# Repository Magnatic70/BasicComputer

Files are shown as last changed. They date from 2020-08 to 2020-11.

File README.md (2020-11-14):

# BasicComputer
A text-only basic computer with VGA-output using a ESP32/ESP8266 and a FPGA

## What it does
It is a simple computer with a BASIC-interpreter that is close to the one of the Sinclair ZX Spectrum. The computer is text-based only, but does support 8 colors for both foreground and background.

The computer has a 80x60 character display with a 640x480 resolution. You can use a PS2-keyboard connected to the FPGA-board or a HTML-based keyboard using a browser as input.

There are BASIC-commands for http-based communication (both incoming and outgoing), reading and writing of programs to SPIFFS, reading and writing of data to SPIFFS.

## Thanks to Robin Edwards for the BASIC-interpreter
I didn't write the core of the BASIC-interpreter myself, but it is based on https://github.com/robinhedwards/ArduinoBASIC by Robin Edwards.

I did adapt the interpreter so that it can be used on an ESP. An ESP needs variables to be 4 byte aligned in memory. The Arduino does not have that restriction. The interpreter stored variables directly into a pool of reserved memory which of course was almost never 4 byte aligned. By converting variables into separate bytes and then storing those bytes I managed to use the same approach with as little changes to the interpreter as possible.

I also added al lot of new commands and functions regarding mainly http-communication, reading and writing to SPIFFS and some other useful stuff. And most importantly, I wrote a new host-interface for the intepreter that allows the ESP to communicate with the FPGA and/or the HTML-keyboard-interface.

## Components, tools and software required
* ESP32: I use a D1 Mini ESP32 (https://www.aliexpress.com/item/32816065152.html)
* (Alternative) ESP8266: D1 Mini ESP8266 (https://www.aliexpress.com/item/32651747570.html)
* FPGA-board:  I use a A-C4E6E10 with an Cyclone IV EP4CE6E22C8 (https://www.aliexpress.com/item/4001125259366.html) but other FPGA-boards may also work. The FPGA-program needs 953 logical elements, 258 registers, 11 pins, 4688 bits of on-chip memory and 1 on-chip pll. The source in this repository has all pins assigned, but they most likely won't work for other boards. Also the optional 3D-printed case probably won't fit.
* USB-blaster or other JTAG-programmer for uploading to the FPGA
* VGA-monitor
* (Optional) PS/2 keyboard
* Five wires (M-F) to connect the ESP32 and FPGA-board
* Arduino-IDE to compile and upload to the ESP32
* Quartus Prime 19.1 Lite Edition with support for the Cyclone IV-family to compile and upload to the FPGA
* (Optional) 3D-printer to print the case for the computer
* (Optional) Two small screws to join the two parts of the case and four small screws to join the FPGA-board to the bottom of the case.

Using the ESP8266 instead of the ESP32 will result in a lot less memory available for BASIC-programs. The ESP32 has 113792 bytes available for BASIC where the ESP8266 has just 16384 bytes available.

## How to make it
### ESP
#### Compilation
1. Download all files from https://github.com/Magnatic70/magnatic-esp, except magnatic-esp.ino and add these files to the ones in this projects esp-source folder.
1. Use the Arduino-IDE to load, compile and upload BASCOMP002.ino to the ESP.

If you don't have a PS/2-keyboard
1. Follow the instructions in https://github.com/Magnatic70/magnatic-esp/blob/master/README.md chapters "First deployment" and "Initial configuration"
1. Upload the file keyboard.html with WinSCP to the ESP

The ESP is now ready for use.

### FPGA
1. Load asciiVGAVideoCard.qpf in Quartus Prime and Start Compilation
1. File --> Convert programming files --> Open conversion Setup Data -->  sof2jic4cycloneiv.cof --> Open --> Generate
1. Programmer --> Add file --> output_files/asciiVGACard.jic --> Open --> Check the Program/Configure checkbox in the second line --> Start

The FPGA-board is now ready for use.

### Connect ESP and FPGA
For a D1 Mini ESP32
1. Connect FPGA-pin GND to ESP-pin GND
1. Connect FPGA-pin 3.3V to ESP-pin 3.3V
1. Connect FPGA-pin 30 to ESP-pin IO17 (TX UART2)
1. Connect FPGA-pin 28 to ESP-pin IO16 (RX UART2)
1. Connect FPGA-pin 32 to ESP-pin IO21

For a D1 Mini ESP8266
1. Connect FPGA-pin GND to ESP-pin GND
1. Connect FPGA-pin 3.3V to ESP-pin 3.3V
1. Connect FPGA-pin 30 to ESP-pin TX
1. Connect FPGA-pin 28 to ESP-pin RX
1. Connect FPGA-pin 32 to ESP-pin D1

Your BASIC-computer should now work. Connect a VGA-monitor and (optional) PS/2-keyboard to the FPGA-board and power on the board.

If you have a PS/2-keyboard you can start using the BASIC-computer right awys. You can connect the computer to your Wifi-network using the commands SETSSID and SETSSIDPW.

If you don't have a PS/2-keyboard you can use the HTML-based keyboard (if you did upload keyboard.html to the ESP) by going to the URL at the top of the screen. As long as the browser-window is active all keyboard-activity is sent to the ESP. If you haven't configured the wifi-settings yet: Connect your wifi to the Wifi-network with BASCOMP in the name. Password: esp

Type HELP or HELP2 for the available BASIC-commands and functions and HELP3 for cursor navigation cues.

### (Optional) 3D-print
1. Print the bottom.stl with a layer height of 0.2mm, no supports needed, infill 10%
1. Print the top.stl with a layer height of 0.2mm, SUPPORTS NEEDED!, infill 10%
1. Remove supports

### (Optional) Place ESP and FPGA in 3D-printed case
1. Use four small screws to mount the FPGA-board to the bottom of the case.
1. Place the ESP in the small space in one of the sides of the top of the case. The springiness of the wires will keep the ESP in that position.
1. Align top and bottom and use two screws at the bottom of the case to join the two parts.

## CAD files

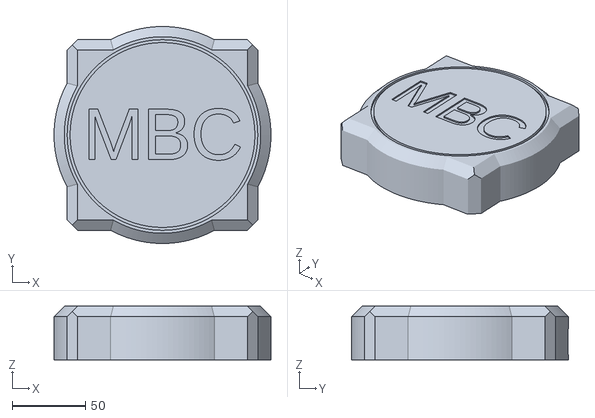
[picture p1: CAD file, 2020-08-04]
3d-printing-code/top.stl
148.0 x 148.0 x 36.5

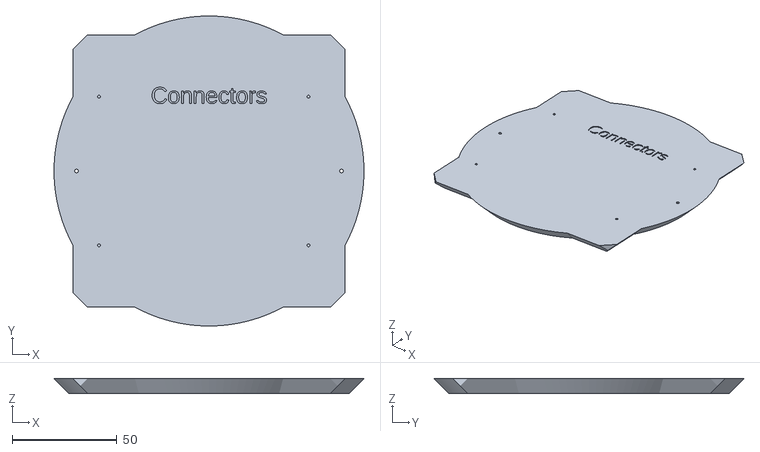
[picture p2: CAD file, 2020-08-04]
3d-printing-code/bottom.stl
148.0 x 148.0 x 7.00

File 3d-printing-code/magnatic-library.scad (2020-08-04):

module myCylinder(radius,height,chamfer){
  union(){
    cylinder(h=chamfer,r1=radius-chamfer,r2=radius);
    translate([0,0,chamfer]){
      cylinder(h=height-2*chamfer,r=radius);
    }
    translate([0,0,height-chamfer]){
      cylinder(h=chamfer,r1=radius,r2=radius-chamfer);
    }
  }
}

module myCylinderCTop(radius,height,chamfer){
  union(){
    cylinder(h=height-chamfer,r=radius);
    translate([0,0,height-chamfer]){
      cylinder(h=chamfer,r1=radius,r2=radius-chamfer);
    }
  }
}

module myCylinderCBottom(radius,height,chamfer){
  union(){
    cylinder(h=chamfer,r1=radius-chamfer,r2=radius);
    translate([0,0,chamfer]){
      cylinder(h=height-chamfer,r=radius);
    }
  }
}

module hollowCylinder(height,outerRadius,innerRadius,chamfer){
  difference(){
    myCylinder(outerRadius,height,chamfer);
    union(){
      translate([0,0,-0.001]){
        cylinder(h=chamfer+0.002,r1=innerRadius+chamfer,r2=innerRadius);
      }
      translate([0,0,chamfer-0.001]){
        cylinder(h=height-2*chamfer+0.002,r=innerRadius);
      }
      translate([0,0,height-chamfer-0.001]){
        cylinder(h=chamfer+0.002,r1=innerRadius,r2=innerRadius+chamfer);
      }
    }
  }
}

module chamferCube(sizeX, sizeY, sizeZ, chamferHeight, center, chamferX, chamferY, chamferZ) {
  chamferX = (chamferX == undef) ? [1, 1, 1, 1] : chamferX;
  chamferY = (chamferY == undef) ? [1, 1, 1, 1] : chamferY;
  chamferZ = (chamferZ == undef) ? [1, 1, 1, 1] : chamferZ;
  chamferCLength = sqrt(chamferHeight * chamferHeight * 2);
  tx=center?-(sizeX/2):0;
  ty=center?-(sizeY/2):0;
  tz=center?-(sizeZ/2):0;
  translate([tx,ty,tz]){
    difference() {
      cube([sizeX, sizeY, sizeZ]);
      for(x = [0 : 3]) {
        chamferSide1 = min(x, 1) - floor(x / 3); // 0 1 1 0
        chamferSide2 = floor(x / 2); // 0 0 1 1
        if(chamferX[x]) {
          translate([-0.1, chamferSide1 * sizeY, -chamferHeight + chamferSide2 * sizeZ]){
            rotate([45, 0, 0]){
              cube([sizeX + 0.2, chamferCLength, chamferCLength]);
            }
          }
        }
        if(chamferY[x]) {
          translate([-chamferHeight + chamferSide2 * sizeX, -0.1, chamferSide1 * sizeZ]){
            rotate([0, 45, 0]){
              cube([chamferCLength, sizeY + 0.2, chamferCLength]);
            }
          }
        }
        if(chamferZ[x]) {
          translate([chamferSide1 * sizeX, -chamferHeight + chamferSide2 * sizeY, -0.1]){
            rotate([0, 0, 45]){
              cube([chamferCLength, chamferCLength, sizeZ + 0.2]);
            }
          }
        }
      }
    }
  }
}

module wedge(width1,width2,depth,height){
  linear_extrude(height = height) {
    polygon(points=[[0,0],[width2,0],[width1,depth]]);
  }
}

module torus(r1, r2){
  rotate_extrude(){
    translate([r1,0,0]){
      circle(r2);
    }
  }
}

module myText(line,size,depth,detail){
  linear_extrude(height = depth) {
    text(line, size = size, font = "Liberation Sans", halign = "center", valign = "center", $fn = detail);
  }
}

module myPolyhedron(points){ // Simplified version of polyhedron, suitable for 6-sided polyhedrons
  // Define points as follows: Begin at 0,0 than counter clockwise all points for the underside than the upside
  faces=[
    [0,1,2,3],  // bottom
    [4,5,1,0],  // front
    [7,6,5,4],  // top
    [5,6,2,1],  // right
    [6,7,3,2],  // back
    [7,4,0,3]   // left
  ];
  polyhedron(points=points,faces=faces);
}

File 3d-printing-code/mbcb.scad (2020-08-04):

include <magnatic-library.scad>

$fn=128;

bigChamfer=7;
width=130;
height=43.5;
radiusOverWidth=9;
radius=width/2+radiusOverWidth;
boardXOffset=0.5;
boardYOffset=13.5;

module case(){
  difference(){
    union(){
      chamferCube(width,width,height,bigChamfer);
      translate([width/2,width/2,0]){
        myCylinder(radius,height,bigChamfer);
      }
    }
    translate([width/2,width/2,height-2]){
      hollowCylinder(2.1,width/2,width/2-2,0);
    }
    translate([width/2,width/2,height-1]){
      myText("MBC",36,1.1,128);
    }
    translate([bigChamfer,bigChamfer,bigChamfer]){
      cube([113,102+16,33]); // Chamber for board
    }
    translate([bigChamfer+boardXOffset+2,bigChamfer+boardYOffset+101,bigChamfer+3.5]){
      cube([64,20,17.5]); // Hole for connectors
    }
    translate([bigChamfer+38,0,bigChamfer]){
      cube([42,8,33]); // Chamber for ESP
    }
    
    // Holes for screws
    translate([bigChamfer/4,width/2,-0.1]){
      cylinder(r=4.8/2,h=bigChamfer-2);
    }
    translate([width-bigChamfer/4,width/2,-0.1]){
      cylinder(r=4.8/2,h=bigChamfer-2);
    }
    translate([bigChamfer/4,width/2,-0.1]){
      cylinder(r=1.8/2,h=bigChamfer+19);
    }
    translate([width-bigChamfer/4,width/2,-0.1]){
      cylinder(r=1.8/2,h=bigChamfer+19);
    }
  }
}

module ac4e6e10(){
  color("Green"){
    cube([112,101,20]);
  }
  translate([32,101,5]){
    color("Blue"){
      cube([31,7,14]);
    }
  }
  translate([80,101,5]){
    color("Black"){
      cube([31,7,14]);
    }
  }
}
  
module caseUnderside(){
  difference(){
    case();
    translate([-0.1-radiusOverWidth,-0.1-radiusOverWidth,bigChamfer]){
      cube([width+0.2+2*radiusOverWidth,width+0.2+2*radiusOverWidth,height-bigChamfer+0.1]);
    }
    // Screw holes for board placement
    translate([bigChamfer+boardXOffset,bigChamfer+boardYOffset,3.1]){
      translate([5,9,0]){
        cylinder(r=0.7,h=5);
      }
      translate([5,80,0]){
        cylinder(r=0.7,h=5);
      }
      translate([112-7,80,0]){
        cylinder(r=0.7,h=5);
      }
      translate([112-7,9,0]){
        cylinder(r=0.7,h=5);
      }
    }
    translate([width/2,101,bigChamfer-0.5]){
      myText("Connectors",8,0.6,16);
    }
  }
}

module caseTop(){
  difference(){
    case();
    translate([-0.1-radiusOverWidth,-0.1-radiusOverWidth,-0.1]){
      cube([width+0.2+2*radiusOverWidth,width+0.2+2*radiusOverWidth,bigChamfer+0.11]);
    }
  }
}

caseUnderside();

//caseTop();

translate([bigChamfer+boardXOffset,bigChamfer+boardYOffset,bigChamfer]){
  //ac4e6e10();
}

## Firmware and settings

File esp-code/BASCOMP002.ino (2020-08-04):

// v001:	* First version
// v002:	* Changed from magnatic-esp8266 to magnatic-esp

#include "magnatic-esp.h"
#include "bcbasic.h"

void setup(){
	pinMode(ActivePin,OUTPUT);
	digitalWrite(ActivePin,LOW);
	magnaticDeviceDescription="BasicComputer";
	magnaticDeviceType="BASCOMP";
	magnaticDeviceTypeIndexFileSize=706;
	getDeviceReleaseFromSourceFile(__FILE__);

	espSetup();
	basicSetup();
}

void loop(){
	basicLoop(); // The espLoop is performed within the basicLoop
}

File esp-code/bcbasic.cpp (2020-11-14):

/* ---------------------------------------------------------------------------
 * Originally from Robin Edwards. Modified for use on ESP-devices.
 * Thanks to Robin Edwards for this excellent basic interpreter!
 * 
 * Basic Interpreter
 * Robin Edwards 2014
 * ---------------------------------------------------------------------------
 * This BASIC is modelled on Sinclair BASIC for the ZX81 and ZX Spectrum. It
 * should be capable of running most of the examples in the manual for both
 * machines, with the exception of anything machine specific (i.e. graphics,
 * sound & system variables).
 *
 * Notes
 *  - All numbers (except line numbers) are floats internally
 *  - Multiple commands are allowed per line, seperated by :
 *  - LET is optional e.g. LET a = 6: b = 7
 *  - MOD provides the modulo operator which was missing from Sinclair BASIC.
 *     Both numbers are first rounded to ints e.g. 5 mod 2 = 1
 *  - CONT can be used to continue from a STOP. It does not continue from any
 *     other error condition.
 *  - Arrays can be any dimension. There is no single char limit to names.
 *  - Like Sinclair BASIC, DIM a(10) and LET a = 5 refer to different 'a's.
 *     One is a simple variable, the other is an array. There is no ambiguity
 *     since the one being referred to is always clear from the context.
 *  - String arrays differ from Sinclair BASIC. DIM a$(5,5) makes an array
 *     of 25 strings, which can be any length. e.g. LET a$(1,1)="long string"
 *  - functions like LEN, require brackets e.g. LEN(a$)
 *  - String manipulation functions are LEFT$, MID$, RIGHT$
 *  - RND is a nonary operator not a function i.e. RND not RND()
 *  - LIST takes an optional start and end e.g. LIST 1,100 or LIST 50
 * ---------------------------------------------------------------------------
 */

// Enable debugging:
// 		Search for: //serial.print(.*?);
//		Replace with: //Serial.print\1; //debug 

// Disable debugging:
//		Search for: serial.print(.*?)//debug
// 		Replace with: //Serial.print\1

#include "magnatic-esp.h"

#include <stdio.h>
#include <stdlib.h>
#include <string.h>
#include <ctype.h>
#include <math.h>
#include <float.h>
#include <limits.h>

#include "bcbasic.h"

#define basicX 80
#define basicY 60

//char basicScreen[basicX*basicY];
//char basicScreenColor[basicX*basicY];
char * basicScreen;
char * basicScreenColor;
char lineDirty[basicY];
int hostX=0;
int hostY=0;

int sysPROGEND;
int sysSTACKSTART, sysSTACKEND;
int sysVARSTART, sysVAREND;
int sysGOSUBSTART, sysGOSUBEND;
int MEMORY_SIZE;
char inputMode = 0;
char inkeyChar = 0;
bool flashCursor=true;
unsigned long nextFlashCursorEvent=0;
char fgColor=COLOR_WHITE;
char bgColor=COLOR_BLUE;
bool programRunning=false;

WiFiClient basicOutput;
int freeHeapAfterBasicRun=0;
unsigned long scriptRuntime=0;
bool outputEnabled=false;
String libraryTimeBasic=__TIMESTAMP__;
String scriptTrigger;
File basicFile;
String basicFilename;
int basicFileReadPosition=0;
int basicFileWritePosition=0;
bool basicFileOpen=false;
String basicHttpRecvParamName="value";
String basicHttpRecvParamValue="";
bool httpRecvAvailable=false;
bool httpKeyAvailable=false;
char httpKey;

char string_0[] = "OK";
char string_1[] = "Bad number";
char string_2[] = "Line too long";
char string_3[] = "Unexpected input";
char string_4[] = "Unterminated string";
char string_5[] = "Missing bracket";
char string_6[] = "Error in expr";
char string_7[] = "Numeric expr expected";
char string_8[] = "String expr expected";
char string_9[] = "Line number too big";
char string_10[] = "Out of memory";
char string_11[] = "Div by zero";
char string_12[] = "Variable not found";
char string_13[] = "Bad command";
char string_14[] = "Bad line number";
char string_15[] = "Break pressed";
char string_16[] = "NEXT without FOR";
char string_17[] = "STOP statement";
char string_18[] = "Missing THEN in IF";
char string_19[] = "RETURN without GOSUB";
char string_20[] = "Wrong array dims";
char string_21[] = "Bad array index";
char string_22[] = "Bad string index";
char string_23[] = "Error in VAL input";
char string_24[] = "Bad parameter";
char string_25[] = "File not open";
char string_26[] = "Structure larger than 65535 bytes";

char* errorTable[] = {
    string_0, string_1, string_2, string_3,
    string_4, string_5, string_6, string_7,
    string_8, string_9, string_10, string_11,
    string_12, string_13, string_14, string_15,
    string_16, string_17, string_18, string_19,
    string_20, string_21, string_22, string_23,
    string_24, string_25, string_26
};

// Host-functions
char bytesFreeStr[] = "bytes free";

// Token flags
// bits 1+2 number of arguments
#define TKN_ARGS_NUM_MASK	0x03
// bit 3 return type (set if string)
#define TKN_RET_TYPE_STR	0x04
// bits 4-6 argument type (set if string)
#define TKN_ARG1_TYPE_STR	0x08
#define TKN_ARG2_TYPE_STR	0x10
#define TKN_ARG3_TYPE_STR	0x20

#define TKN_ARG_MASK		0x38
#define TKN_ARG_SHIFT		3
// bits 7,8 formatting
#define TKN_FMT_POST		0x40
#define TKN_FMT_PRE		0x80

//unsigned char mem[MEMORY_SIZE];
unsigned char * mem;
unsigned char tokenBuf[TOKEN_BUF_SIZE];
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
